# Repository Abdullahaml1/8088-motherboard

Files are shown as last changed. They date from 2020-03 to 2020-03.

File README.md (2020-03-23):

# 8088-motherboard
This is the full design files for the  20x20 cm^2 8088 motheboard project.

The project aims to uplaoad a code on the flash memories of the intel 8088 micro processor  with 8051 controller. In addtion input outpu module addes to test inputs.

The motherboard consists of 5 parts:

1. The motherboard it self with the 8088 in its center. 
2. The 80851 module.
3. The input output module.
4. two memories.

# Table of Content

* [Full desing](#Full-Desing)
* [8088 Motherboard](#8088-Motherboard)
* [8051 Module](#8051-Module)
* [Input Output Module](#Input-Output-Module)
* [Memories](#Memories)

## Full Desing

top view

side view

## 8088 Motherboard

empty mothrboard

## 8051 Module

8051 module

## Input Output Module

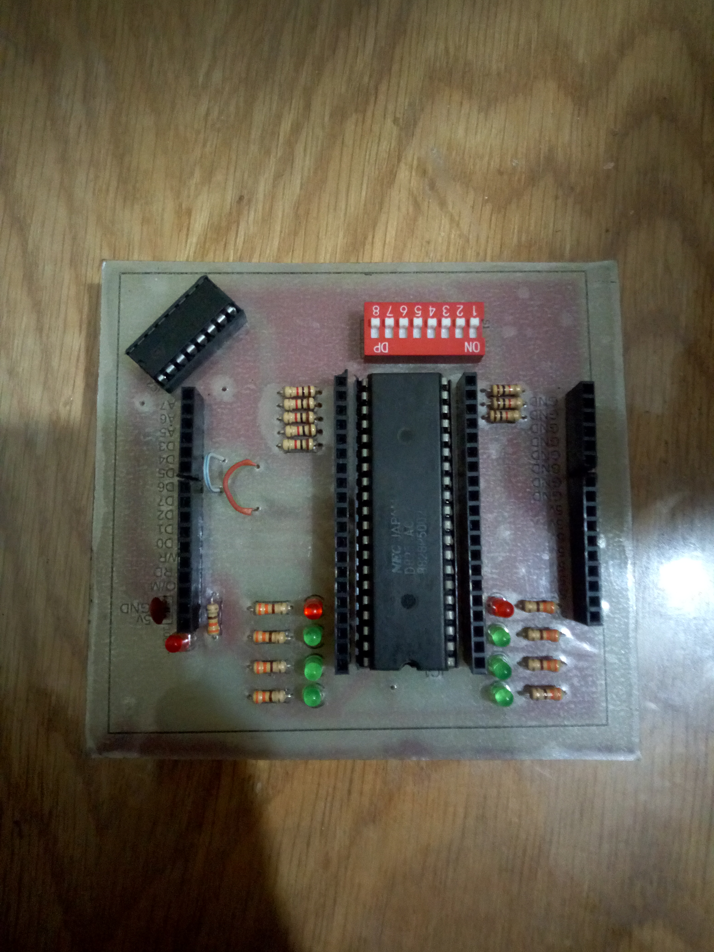
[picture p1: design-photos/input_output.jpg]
input output module


## Memories 

Memories

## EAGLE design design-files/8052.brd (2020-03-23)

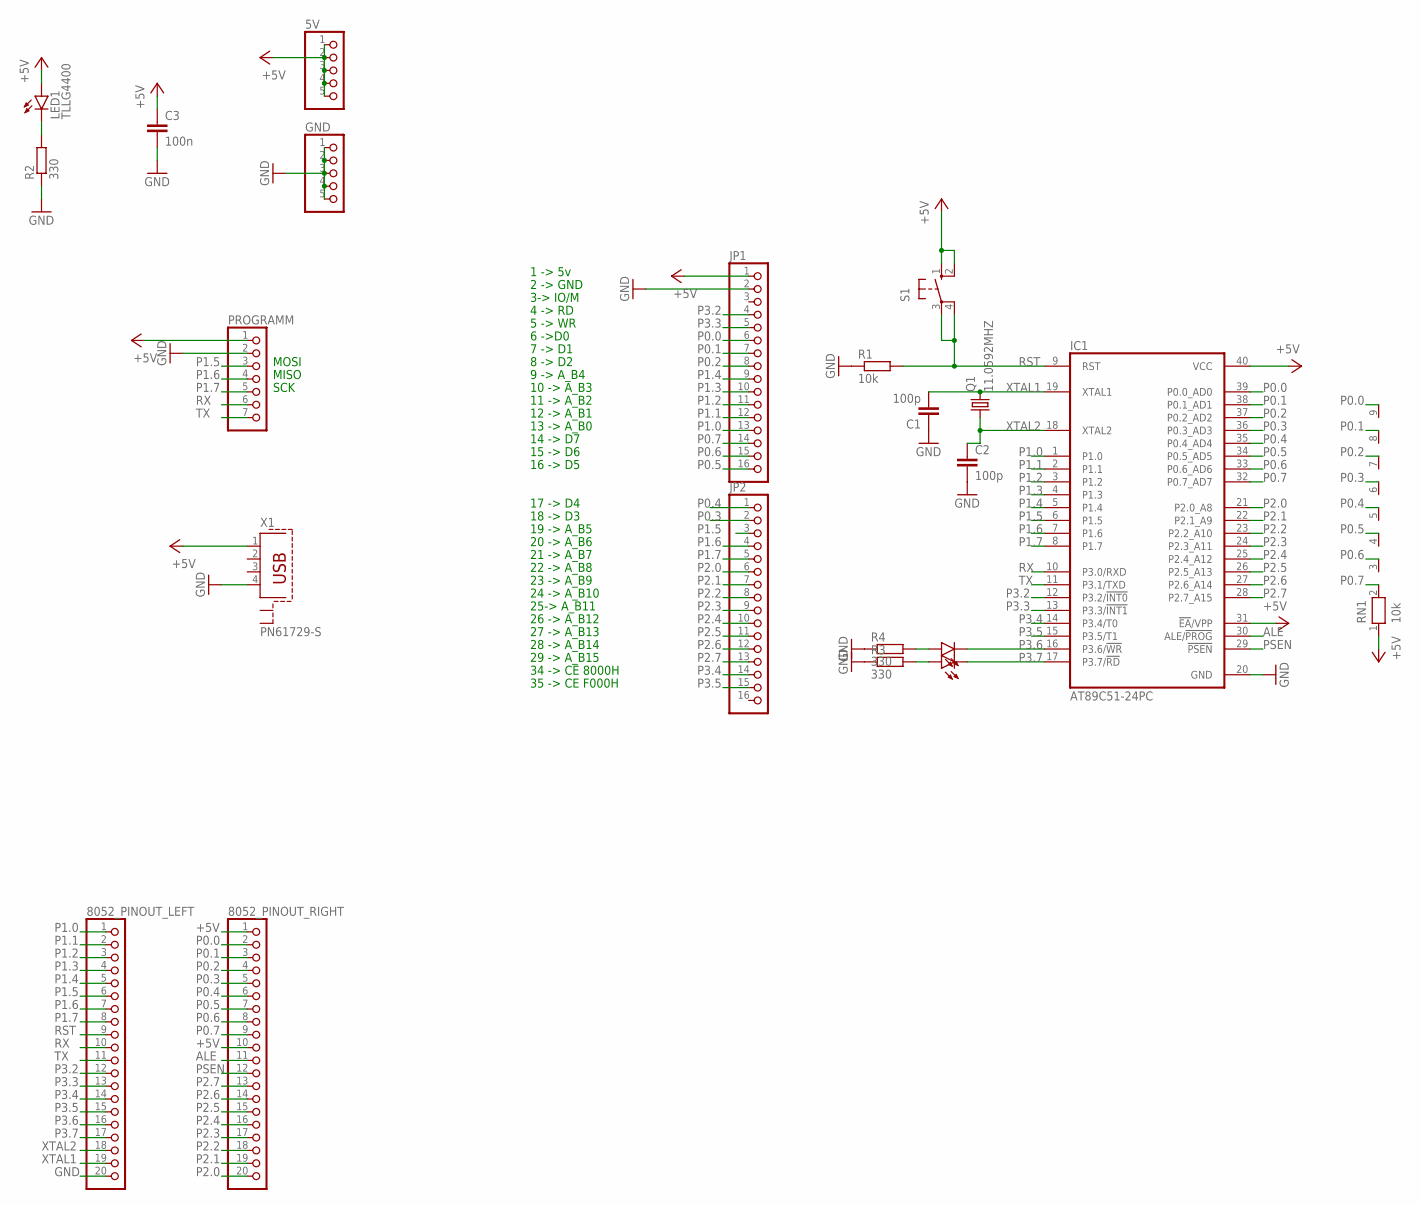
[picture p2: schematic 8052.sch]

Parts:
5V: PINHD-1X5; 1X05
8052_PINOUT_LEFT, 8052_PINOUT_RIGHT: PINHD-1X20; 1X20
C1, C2: 100p; C025-024X044
C3: 100n; C025-025X050
GND: PINHD-1X5; 1X05
IC1: AT89C51-24PC; DIL40
JP1, JP2: PINHD-1X16; 1X16
LED1, LED2, LED3: TLLG4400; LED3MM
PROGRAMM: PINHD-1X7/90; 1X07/90
Q1: 11.0592MHZ; HC49/S
R1: 10k; 0207/7
R2, R3, R4: 330; 0207/7
RN1: 10k; RN-9
S1: 10-XX; B3F-10XX
X1: PN61729-S

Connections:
+5V: 5V.1, 5V.2, 5V.3, 5V.4, 5V.5, 8052_PINOUT_RIGHT.1, 8052_PINOUT_RIGHT.10, C3.1, IC1.31 (!EA!/VPP), IC1.40 (VCC), JP1.1, LED1.A, PROGRAMM.1, RN1.1, S1.1 (S), S1.2 (S1), X1.1
ALE: 8052_PINOUT_RIGHT.11, IC1.30 (ALE/!PROG)
GND: 8052_PINOUT_LEFT.20, C1.1, C2.2, C3.2, GND.1, GND.2, GND.3, GND.4, GND.5, IC1.20 (GND), JP1.2, PROGRAMM.2, R1.1, R2.1, R3.1, R4.1, X1.4
unnamed: LED1.K (C), R2.2
unnamed: LED3.A, R3.2
unnamed: LED2.A, R4.2
P0.0: 8052_PINOUT_RIGHT.2, IC1.39 (P0.0_AD0), JP1.6, RN1.9
P0.1: 8052_PINOUT_RIGHT.3, IC1.38 (P0.1_AD1), JP1.7, RN1.8
P0.2: 8052_PINOUT_RIGHT.4, IC1.37 (P0.2_AD2), JP1.8, RN1.7
P0.3: 8052_PINOUT_RIGHT.5, IC1.36 (P0.3_AD3), JP2.2, RN1.6
P0.4: 8052_PINOUT_RIGHT.6, IC1.35 (P0.4_AD4), JP2.1, RN1.5
P0.5: 8052_PINOUT_RIGHT.7, IC1.34 (P0.5_AD5), JP1.16, RN1.4
P0.6: 8052_PINOUT_RIGHT.8, IC1.33 (P0.6_AD6), JP1.15, RN1.3
P0.7: 8052_PINOUT_RIGHT.9, IC1.32 (P0.7_AD7), JP1.14, RN1.2
P1.0: 8052_PINOUT_LEFT.1, IC1.1 (P1.0), JP1.13
P1.1: 8052_PINOUT_LEFT.2, IC1.2 (P1.1), JP1.12
P1.2: 8052_PINOUT_LEFT.3, IC1.3 (P1.2), JP1.11
P1.3: 8052_PINOUT_LEFT.4, IC1.4 (P1.3), JP1.10
P1.4: 8052_PINOUT_LEFT.5, IC1.5 (P1.4), JP1.9
P1.5: 8052_PINOUT_LEFT.6, IC1.6 (P1.5), JP2.3, PROGRAMM.3
P1.6: 8052_PINOUT_LEFT.7, IC1.7 (P1.6), JP2.4, PROGRAMM.4
P1.7: 8052_PINOUT_LEFT.8, IC1.8 (P1.7), JP2.5, PROGRAMM.5
P2.0: 8052_PINOUT_RIGHT.20, IC1.21 (P2.0_A8), JP2.6
P2.1: 8052_PINOUT_RIGHT.19, IC1.22 (P2.1_A9), JP2.7
P2.2: 8052_PINOUT_RIGHT.18, IC1.23 (P2.2_A10), JP2.8
P2.3: 8052_PINOUT_RIGHT.17, IC1.24 (P2.3_A11), JP2.9
P2.4: 8052_PINOUT_RIGHT.16, IC1.25 (P2.4_A12), JP2.10
P2.5: 8052_PINOUT_RIGHT.15, IC1.26 (P2.5_A13), JP2.11
P2.6: 8052_PINOUT_RIGHT.14, IC1.27 (P2.6_A14), JP2.12
P2.7: 8052_PINOUT_RIGHT.13, IC1.28 (P2.7_A15), JP2.13
P3.2: 8052_PINOUT_LEFT.12, IC1.12 (P3.2/!INT0), JP1.4
P3.3: 8052_PINOUT_LEFT.13, IC1.13 (P3.3/!INT1), JP1.5
P3.4: 8052_PINOUT_LEFT.14, IC1.14 (P3.4/T0), JP2.14
P3.5: 8052_PINOUT_LEFT.15, IC1.15 (P3.5/T1), JP2.15
P3.6: 8052_PINOUT_LEFT.16, IC1.16 (P3.6/!WR), LED2.K (C)
P3.7: 8052_PINOUT_LEFT.17, IC1.17 (P3.7/!RD), LED3.K (C)
PSEN: 8052_PINOUT_RIGHT.12, IC1.29 (!PSEN)
RST: 8052_PINOUT_LEFT.9, IC1.9 (RST), R1.2, S1.3, S1.4 (P1)
RX: 8052_PINOUT_LEFT.10, IC1.10 (P3.0/RXD), PROGRAMM.6
TX: 8052_PINOUT_LEFT.11, IC1.11 (P3.1/TXD), PROGRAMM.7
XTAL1: 8052_PINOUT_LEFT.19, C1.2, IC1.19 (XTAL1), Q1.2
XTAL2: 8052_PINOUT_LEFT.18, C2.1, IC1.18 (XTAL2), Q1.1

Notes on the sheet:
3-> IO/M
6 ->D0
13 -> A_B0
14 -> D7
21 -> A_B7
22 -> A_B8
25-> A_B11
7 -> D1
8 -> D2
9 -> A_B4
10 -> A_B3
11 -> A_B2
12 -> A_B1
15 -> D6
16 -> D5
17 -> D4
18 -> D3
19 -> A_B5
20 -> A_B6
23 -> A_B9
24 -> A_B10
26 -> A_B12
27 -> A_B13
28 -> A_B14
5 -> WR
4 -> RD
1 -> 5v
2 -> GND
29 -> A_B15
34 -> CE 8000H
35 -> CE F000H
MOSI
MISO
SCK

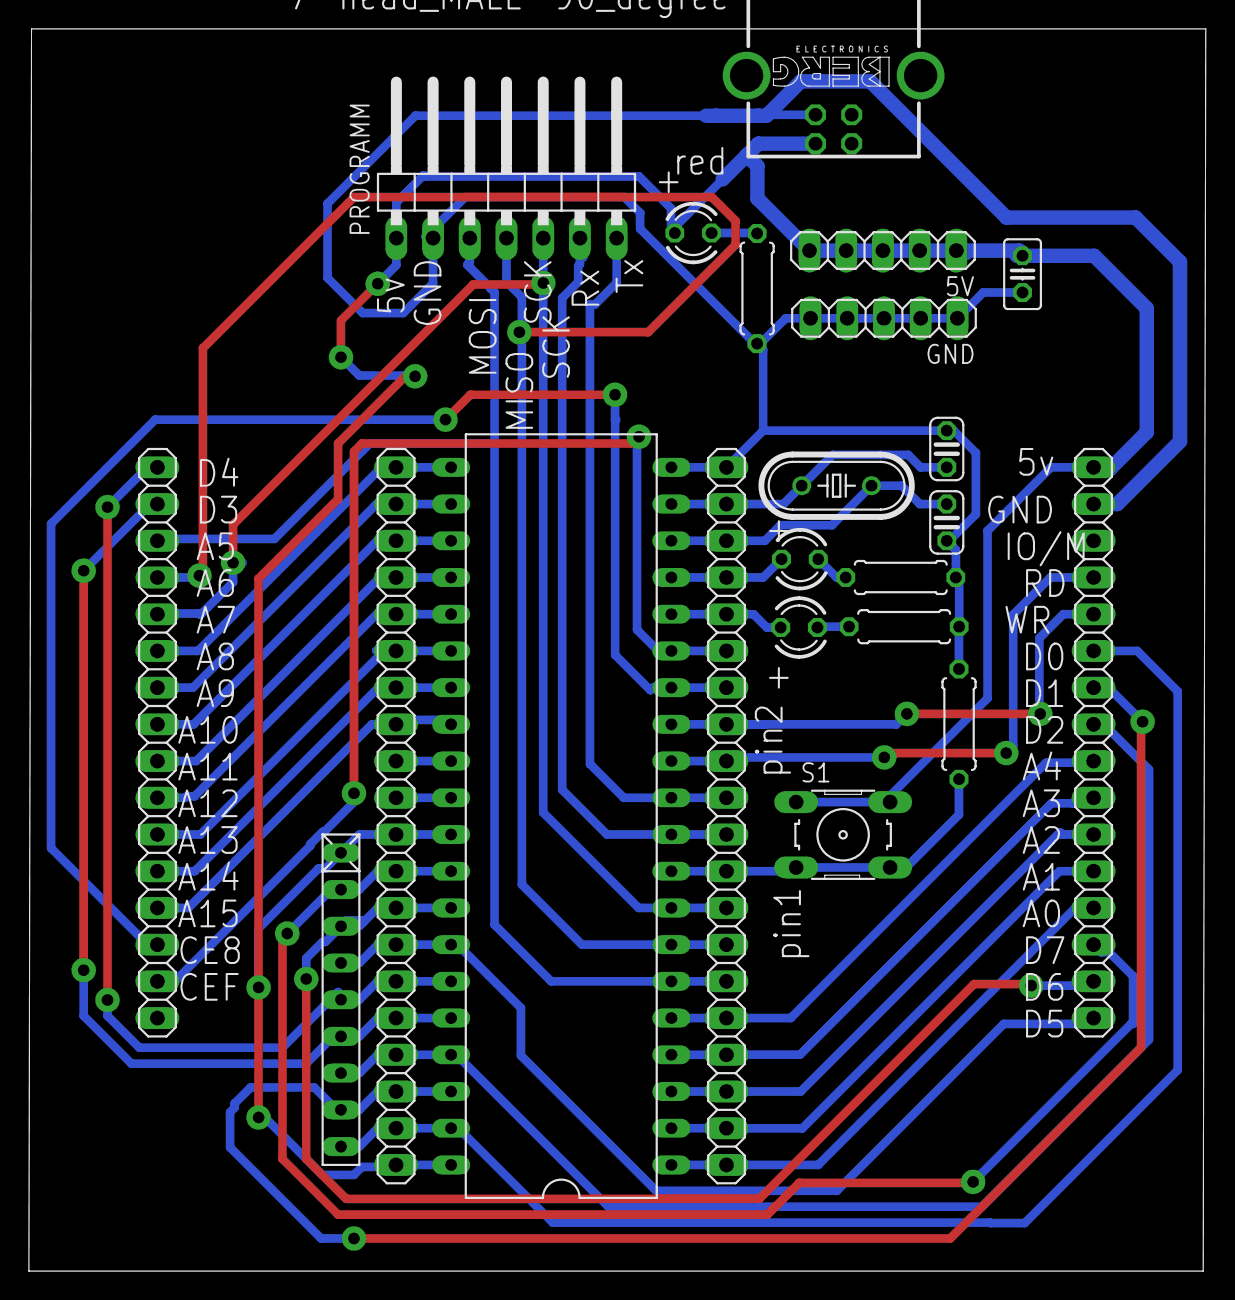
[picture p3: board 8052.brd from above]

Board: 2 copper layers, 81.4 x 85.9 mm, 22 parts (0 on the bottom side), 42 nets.

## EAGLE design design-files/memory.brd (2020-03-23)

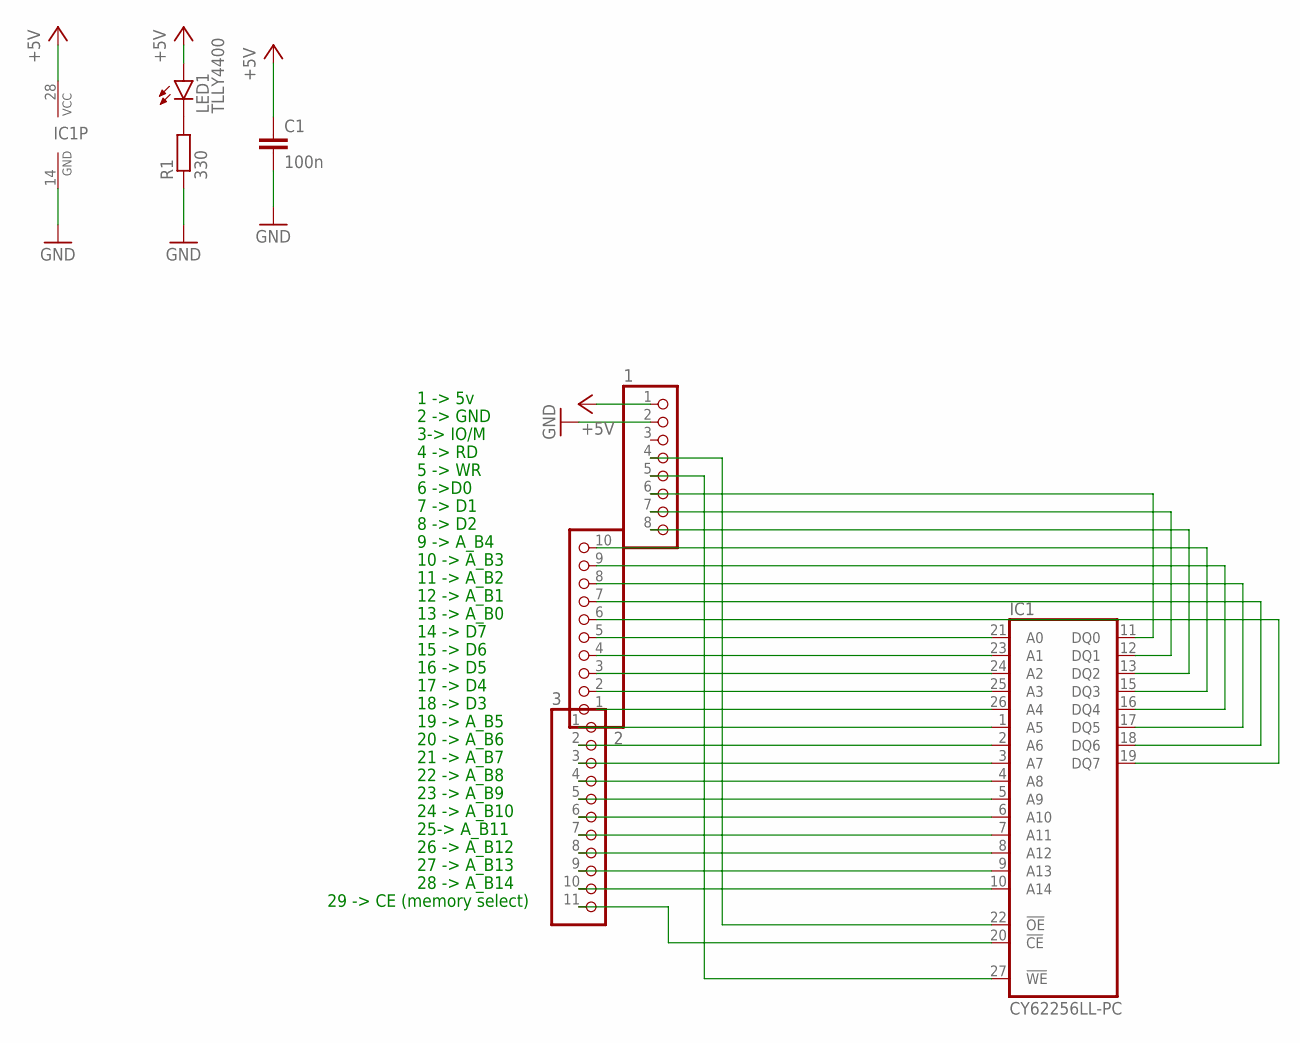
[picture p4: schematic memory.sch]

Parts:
1: PINHD-1X8/90; 1X08/90
2: PINHD-1X10/90; 1X10/90
3: PINHD-1X11/90; 1X11/90
C1: 100n; C025-025X050
IC1: CY62256LL-PC; DIL28-6
LED1: TLLY4400; LED3MM
R1: 330; 0207/7

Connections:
+5V: 1.1, C1.1, IC1.28 (VCC), LED1.A
GND: 1.2, C1.2, IC1.14 (GND), R1.1
unnamed: 2.5, IC1.21 (A0)
unnamed: 2.4, IC1.23 (A1)
unnamed: 2.3, IC1.24 (A2)
unnamed: 2.2, IC1.25 (A3)
unnamed: 2.1, IC1.26 (A4)
unnamed: 3.1, IC1.1 (A5)
unnamed: 3.2, IC1.2 (A6)
unnamed: 3.3, IC1.3 (A7)
unnamed: 3.4, IC1.4 (A8)
unnamed: 3.5, IC1.5 (A9)
unnamed: 3.6, IC1.6 (A10)
unnamed: 3.7, IC1.7 (A11)
unnamed: 3.8, IC1.8 (A12)
unnamed: 3.9, IC1.9 (A13)
unnamed: 3.10, IC1.10 (A14)
unnamed: 1.6, IC1.11 (DQ0)
unnamed: 1.7, IC1.12 (DQ1)
unnamed: 1.8, IC1.13 (DQ2)
unnamed: 2.10, IC1.15 (DQ3)
unnamed: 2.9, IC1.16 (DQ4)
unnamed: 2.8, IC1.17 (DQ5)
unnamed: 2.7, IC1.18 (DQ6)
unnamed: 2.6, IC1.19 (DQ7)
unnamed: LED1.K (C), R1.2
unnamed: 1.5, IC1.27 (!WE)
unnamed: 1.4, IC1.22 (!OE)
unnamed: 3.11, IC1.20 (!CE)

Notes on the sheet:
3-> IO/M
6 ->D0
13 -> A_B0
14 -> D7
21 -> A_B7
22 -> A_B8
25-> A_B11
7 -> D1
8 -> D2
9 -> A_B4
10 -> A_B3
11 -> A_B2
12 -> A_B1
15 -> D6
16 -> D5
17 -> D4
18 -> D3
19 -> A_B5
20 -> A_B6
23 -> A_B9
24 -> A_B10
26 -> A_B12
27 -> A_B13
28 -> A_B14
29 -> CE (memory select)
5 -> WR
4 -> RD
1 -> 5v
2 -> GND

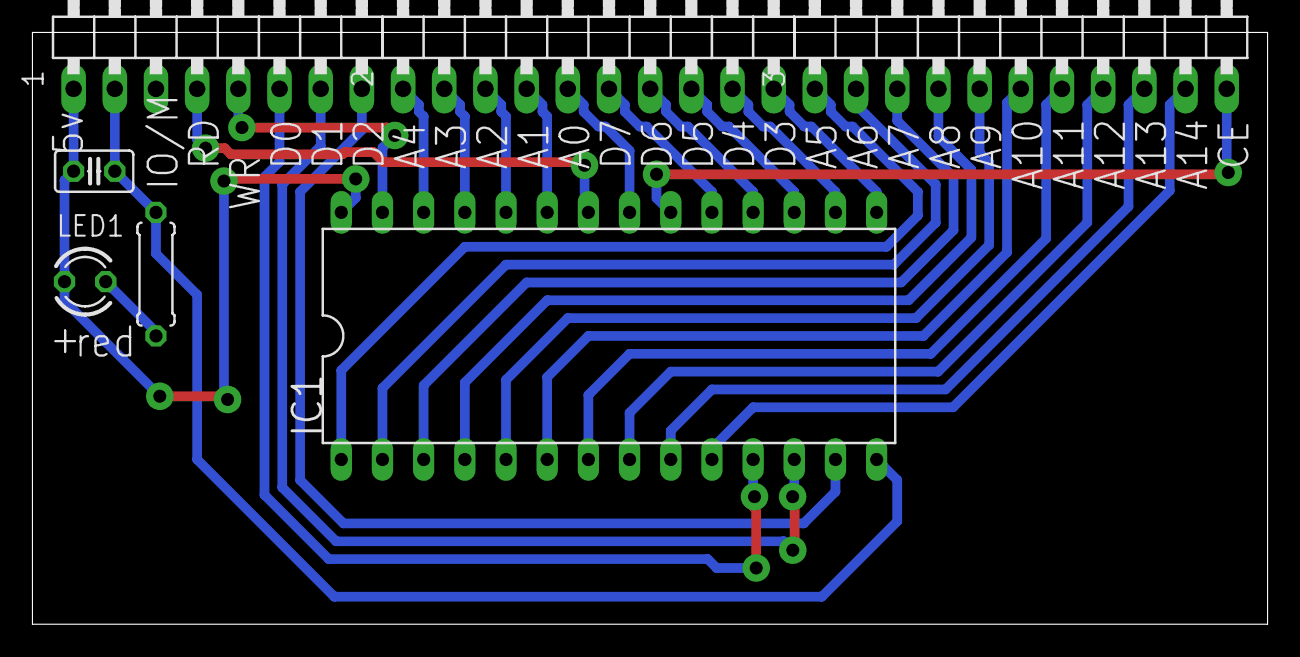
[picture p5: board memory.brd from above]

Board: 2 copper layers, 76.2 x 36.5 mm, 7 parts (0 on the bottom side), 29 nets.

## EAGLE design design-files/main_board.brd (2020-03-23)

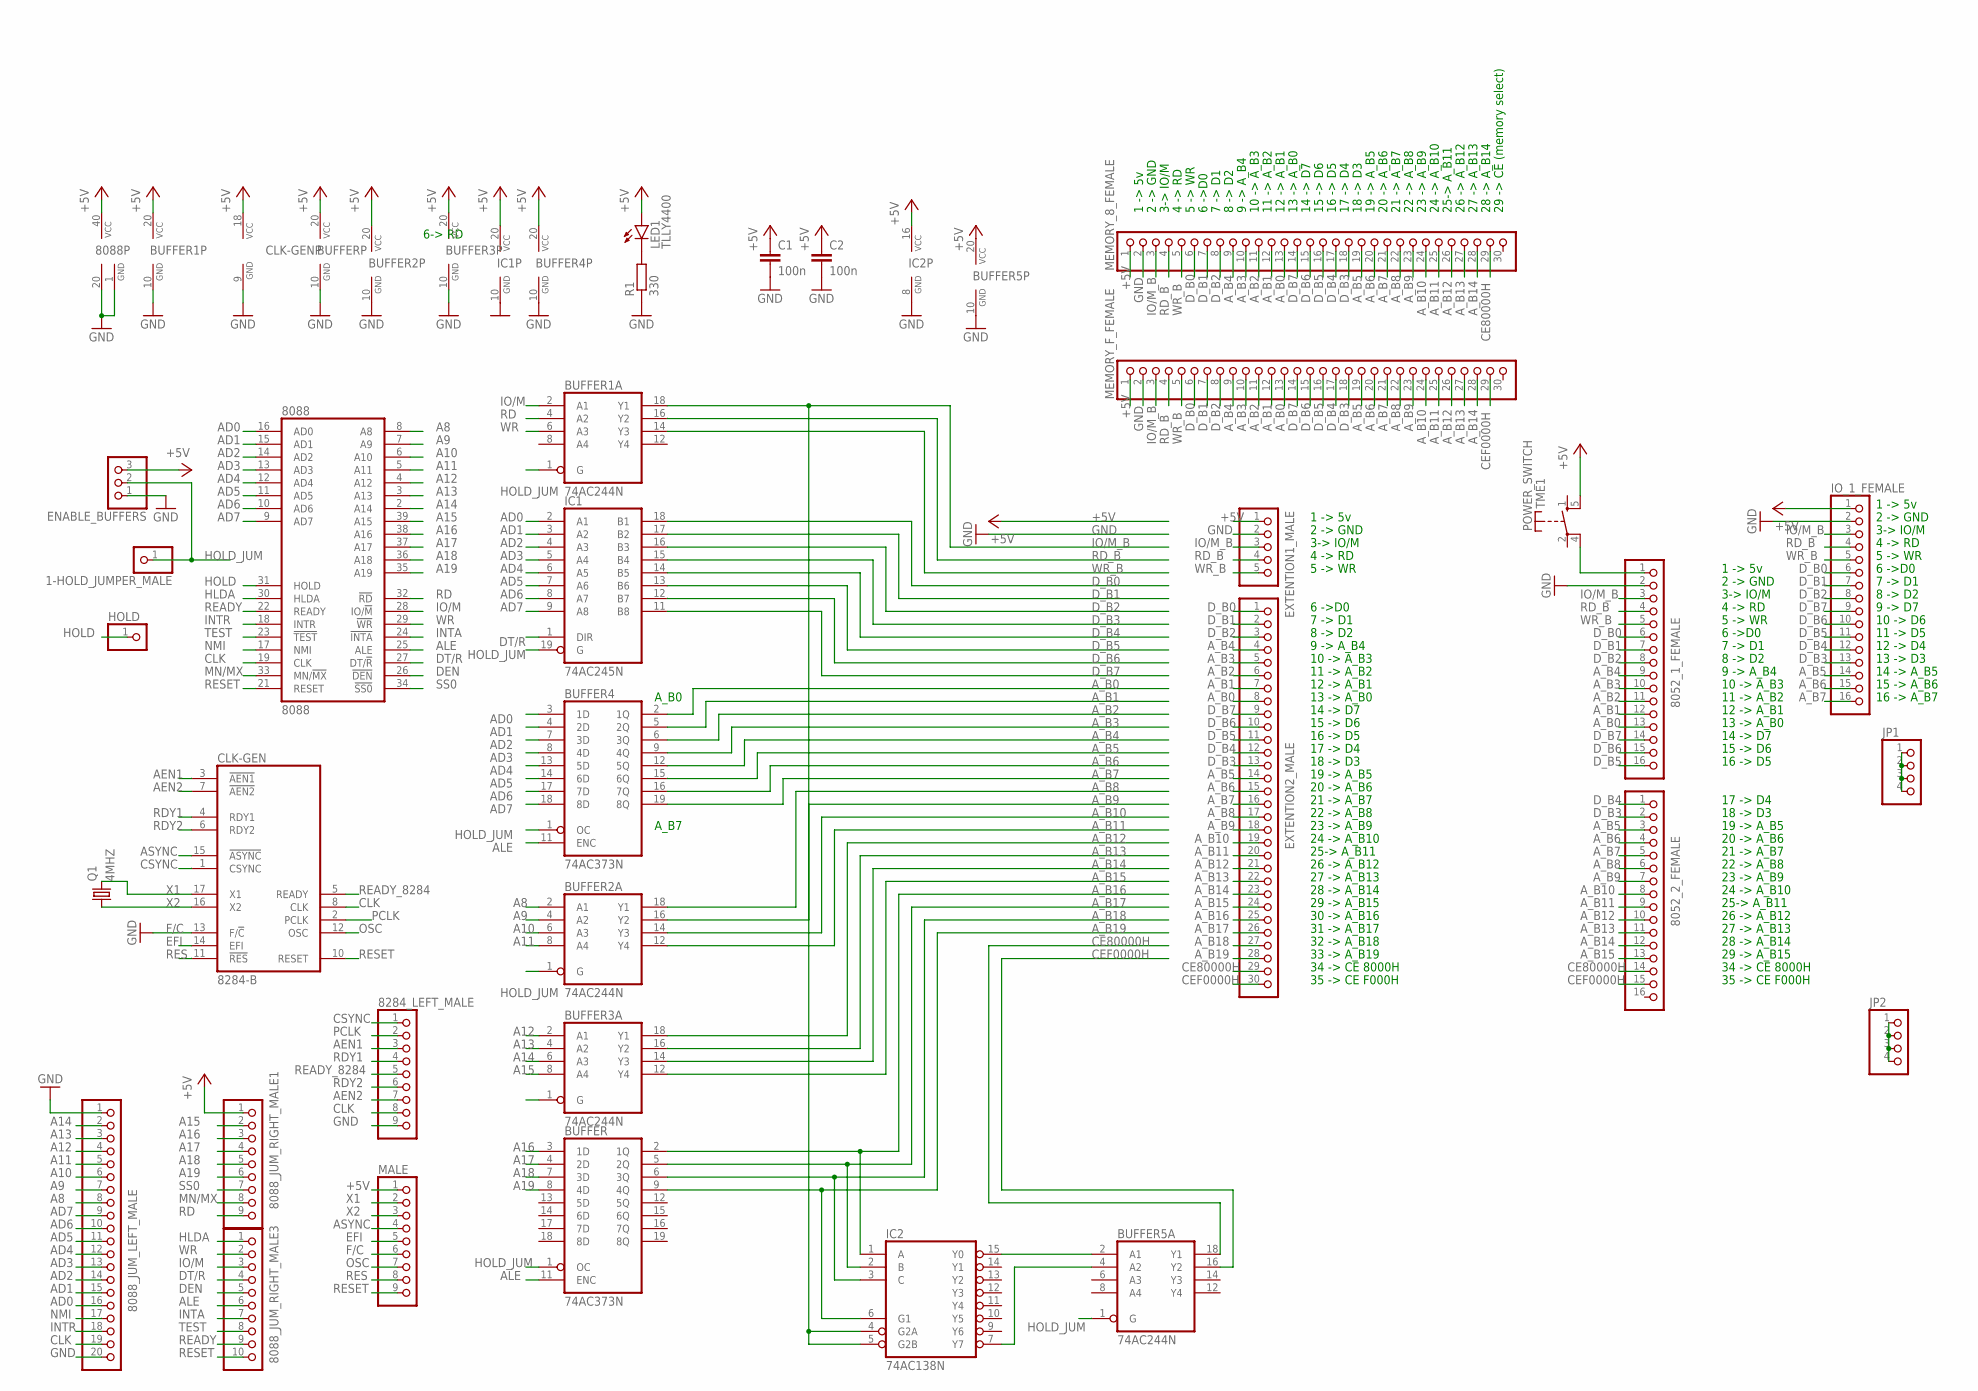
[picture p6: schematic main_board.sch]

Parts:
1-HOLD_JUMPER_MALE: PINHD-1X1; 1X01
8052_1_FEMALE, 8052_2_FEMALE: PINHD-1X16; 1X16
8088: 8088; DIL40
8088_JUM_LEFT_MALE: PINHD-1X20; 1X20
8088_JUM_RIGHT_MALE1, 8284_LEFT_MALE: PINHD-1X9; 1X09
8088_JUM_RIGHT_MALE3: PINHD-1X10; 1X10
BUFFER, BUFFER4: 74AC373N; DIL20
BUFFER1, BUFFER2, BUFFER3, BUFFER5: 74AC244N; DIL20
C1, C2: 100n; C025-025X050
CLK-GEN: 8284-B; DIL18
ENABLE_BUFFERS: PINHD-1X3; 1X03
EXTENTION1_MALE: PINHD-1X5; 1X05
EXTENTION2_MALE: PINHD-1X30; 1X30
HOLD: PINHD-1X1; 1X01
IC1: 74AC245N; DIL20
IC2: 74AC138N; DIL16
IO_1_FEMALE: PINHD-1X16; 1X16
JP1, JP2: PINHD-1X4; 1X04
LED1: TLLY4400; LED3MM
MALE: PINHD-1X9; 1X09
MEMORY_8_FEMALE: PINHD-1X30; 1X30
MEMORY_F_FEMALE: PINHD-1X30; 1X30
POWER_SWITCH: TME1
Q1: 4MHZ; HC49/S
R1: 330; 0204/5

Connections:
+5V: 8088.40 (VCC), 8088_JUM_RIGHT_MALE1.1, BUFFER.20 (VCC), BUFFER1.20 (VCC), BUFFER2.20 (VCC), BUFFER3.20 (VCC), BUFFER4.20 (VCC), BUFFER5.20 (VCC), C1.1, C2.1, CLK-GEN.18 (VCC), ENABLE_BUFFERS.3, EXTENTION1_MALE.1, IC1.20 (VCC), IC2.16 (VCC), IO_1_FEMALE.1, LED1.A, MALE.1, MEMORY_8_FEMALE.1, MEMORY_F_FEMALE.1, POWER_SWITCH.5 (S)
A8: 8088.8 (A8), 8088_JUM_LEFT_MALE.8, BUFFER2.2 (A1)
A9: 8088.7 (A9), 8088_JUM_LEFT_MALE.7, BUFFER2.4 (A2)
A10: 8088.6 (A10), 8088_JUM_LEFT_MALE.6, BUFFER2.6 (A3)
A11: 8088.5 (A11), 8088_JUM_LEFT_MALE.5, BUFFER2.8 (A4)
A12: 8088.4 (A12), 8088_JUM_LEFT_MALE.4, BUFFER3.2 (A1)
A13: 8088.3 (A13), 8088_JUM_LEFT_MALE.3, BUFFER3.4 (A2)
A14: 8088.2 (A14), 8088_JUM_LEFT_MALE.2, BUFFER3.6 (A3)
A15: 8088.39 (A15), 8088_JUM_RIGHT_MALE1.2, BUFFER3.8 (A4)
A16: 8088.38 (A16), 8088_JUM_RIGHT_MALE1.3, BUFFER.3 (1D)
A17: 8088.37 (A17), 8088_JUM_RIGHT_MALE1.4, BUFFER.4 (2D)
A18: 8088.36 (A18), 8088_JUM_RIGHT_MALE1.5, BUFFER.7 (3D)
A19: 8088.35 (A19), 8088_JUM_RIGHT_MALE1.6, BUFFER.8 (4D)
AD0: 8088.16 (AD0), 8088_JUM_LEFT_MALE.16, BUFFER4.3 (1D), IC1.2 (A1)
AD1: 8088.15 (AD1), 8088_JUM_LEFT_MALE.15, BUFFER4.4 (2D), IC1.3 (A2)
AD2: 8088.14 (AD2), 8088_JUM_LEFT_MALE.14, BUFFER4.7 (3D), IC1.4 (A3)
AD3: 8088.13 (AD3), 8088_JUM_LEFT_MALE.13, BUFFER4.8 (4D), IC1.5 (A4)
AD4: 8088.12 (AD4), 8088_JUM_LEFT_MALE.12, BUFFER4.13 (5D), IC1.6 (A5)
AD5: 8088.11 (AD5), 8088_JUM_LEFT_MALE.11, BUFFER4.14 (6D), IC1.7 (A6)
AD6: 8088.10 (AD6), 8088_JUM_LEFT_MALE.10, BUFFER4.17 (7D), IC1.8 (A7)
AD7: 8088.9 (AD7), 8088_JUM_LEFT_MALE.9, BUFFER4.18 (8D), IC1.9 (A8)
AEN1: 8284_LEFT_MALE.3, CLK-GEN.3 (!AEN1)
AEN2: 8284_LEFT_MALE.7, CLK-GEN.7 (!AEN2)
ALE: 8088.25 (ALE), 8088_JUM_RIGHT_MALE3.6, BUFFER.11 (ENC), BUFFER4.11 (ENC)
ASYNC: CLK-GEN.15 (!ASYNC), MALE.4
A_B0: 8052_1_FEMALE.13, BUFFER4.2 (1Q), EXTENTION2_MALE.8, MEMORY_8_FEMALE.13, MEMORY_F_FEMALE.13
A_B1: 8052_1_FEMALE.12, BUFFER4.5 (2Q), EXTENTION2_MALE.7, MEMORY_8_FEMALE.12, MEMORY_F_FEMALE.12
A_B2: 8052_1_FEMALE.11, BUFFER4.6 (3Q), EXTENTION2_MALE.6, MEMORY_8_FEMALE.11, MEMORY_F_FEMALE.11
A_B3: 8052_1_FEMALE.10, BUFFER4.9 (4Q), EXTENTION2_MALE.5, MEMORY_8_FEMALE.10, MEMORY_F_FEMALE.10
A_B4: 8052_1_FEMALE.9, BUFFER4.12 (5Q), EXTENTION2_MALE.4, MEMORY_8_FEMALE.9, MEMORY_F_FEMALE.9
A_B5: 8052_2_FEMALE.3, BUFFER4.15 (6Q), EXTENTION2_MALE.14, IO_1_FEMALE.14, MEMORY_8_FEMALE.19, MEMORY_F_FEMALE.19
A_B6: 8052_2_FEMALE.4, BUFFER4.16 (7Q), EXTENTION2_MALE.15, IO_1_FEMALE.15, MEMORY_8_FEMALE.20, MEMORY_F_FEMALE.20
A_B7: 8052_2_FEMALE.5, BUFFER4.19 (8Q), EXTENTION2_MALE.16, IO_1_FEMALE.16, MEMORY_8_FEMALE.21, MEMORY_F_FEMALE.21
A_B8: 8052_2_FEMALE.6, BUFFER2.18 (Y1), EXTENTION2_MALE.17, MEMORY_8_FEMALE.22, MEMORY_F_FEMALE.22
A_B9: 8052_2_FEMALE.7, BUFFER2.16 (Y2), EXTENTION2_MALE.18, MEMORY_8_FEMALE.23, MEMORY_F_FEMALE.23
A_B10: 8052_2_FEMALE.8, BUFFER2.14 (Y3), EXTENTION2_MALE.19, MEMORY_8_FEMALE.24, MEMORY_F_FEMALE.24
A_B11: 8052_2_FEMALE.9, BUFFER2.12 (Y4), EXTENTION2_MALE.20, MEMORY_8_FEMALE.25, MEMORY_F_FEMALE.25
A_B12: 8052_2_FEMALE.10, BUFFER3.18 (Y1), EXTENTION2_MALE.21, MEMORY_8_FEMALE.26, MEMORY_F_FEMALE.26
A_B13: 8052_2_FEMALE.11, BUFFER3.16 (Y2), EXTENTION2_MALE.22, MEMORY_8_FEMALE.27, MEMORY_F_FEMALE.27
A_B14: 8052_2_FEMALE.12, BUFFER3.14 (Y3), EXTENTION2_MALE.23, MEMORY_8_FEMALE.28, MEMORY_F_FEMALE.28
A_B15: 8052_2_FEMALE.13, BUFFER3.12 (Y4), EXTENTION2_MALE.24
A_B16: BUFFER.2 (1Q), EXTENTION2_MALE.25, IC2.1 (A)
A_B17: BUFFER.5 (2Q), EXTENTION2_MALE.26, IC2.2 (B)
A_B18: BUFFER.6 (3Q), EXTENTION2_MALE.27, IC2.3 (C)
A_B19: BUFFER.9 (4Q), EXTENTION2_MALE.28, IC2.6 (G1)
CE80000H: 8052_2_FEMALE.14, BUFFER5.18 (Y1), EXTENTION2_MALE.29, MEMORY_8_FEMALE.29
CEF0000H: 8052_2_FEMALE.15, BUFFER5.16 (Y2), EXTENTION2_MALE.30, MEMORY_F_FEMALE.29
CLK: 8088.19 (CLK), 8088_JUM_LEFT_MALE.19, 8284_LEFT_MALE.8, CLK-GEN.8 (CLK)
CSYNC: 8284_LEFT_MALE.1, CLK-GEN.1 (CSYNC)
DEN: 8088.26 (!DEN), 8088_JUM_RIGHT_MALE3.5
DT/R: 8088.27 (DT/!R), 8088_JUM_RIGHT_MALE3.4, IC1.1 (DIR)
D_B0: 8052_1_FEMALE.6, EXTENTION2_MALE.1, IC1.18 (B1), IO_1_FEMALE.6, MEMORY_8_FEMALE.6, MEMORY_F_FEMALE.6
D_B1: 8052_1_FEMALE.7, EXTENTION2_MALE.2, IC1.17 (B2), IO_1_FEMALE.7, MEMORY_8_FEMALE.7, MEMORY_F_FEMALE.7
D_B2: 8052_1_FEMALE.8, EXTENTION2_MALE.3, IC1.16 (B3), IO_1_FEMALE.8, MEMORY_8_FEMALE.8, MEMORY_F_FEMALE.8
D_B3: 8052_2_FEMALE.2, EXTENTION2_MALE.13, IC1.15 (B4), IO_1_FEMALE.13, MEMORY_8_FEMALE.18, MEMORY_F_FEMALE.18
D_B4: 8052_2_FEMALE.1, EXTENTION2_MALE.12, IC1.14 (B5), IO_1_FEMALE.12, MEMORY_8_FEMALE.17, MEMORY_F_FEMALE.17
D_B5: 8052_1_FEMALE.16, EXTENTION2_MALE.11, IC1.13 (B6), IO_1_FEMALE.11, MEMORY_8_FEMALE.16, MEMORY_F_FEMALE.16
D_B6: 8052_1_FEMALE.15, EXTENTION2_MALE.10, IC1.12 (B7), IO_1_FEMALE.10, MEMORY_8_FEMALE.15, MEMORY_F_FEMALE.15
D_B7: 8052_1_FEMALE.14, EXTENTION2_MALE.9, IC1.11 (B8), IO_1_FEMALE.9, MEMORY_8_FEMALE.14, MEMORY_F_FEMALE.14
EFI: CLK-GEN.14 (EFI), MALE.5
F/C: CLK-GEN.13 (F/!C), MALE.6
GND: 8052_1_FEMALE.2, 8088.1 (GND), 8088.20 (GND), 8088_JUM_LEFT_MALE.1, 8088_JUM_LEFT_MALE.20, 8284_LEFT_MALE.9, BUFFER.10 (GND), BUFFER1.10 (GND), BUFFER2.10 (GND), BUFFER3.10 (GND), BUFFER4.10 (GND), BUFFER5.10 (GND), C1.2, C2.2, CLK-GEN.9 (GND), ENABLE_BUFFERS.1, EXTENTION1_MALE.2, IC1.10 (GND), IC2.8 (GND), IO_1_FEMALE.2, MEMORY_8_FEMALE.2, MEMORY_F_FEMALE.2, R1.1
HLDA: 8088.30 (HLDA), 8088_JUM_RIGHT_MALE3.1
HOLD: 8088.31 (HOLD), HOLD.1
HOLD_JUM: 1-HOLD_JUMPER_MALE.1, BUFFER.1 (OC), BUFFER1.1 (G), BUFFER2.1 (G), BUFFER4.1 (OC), BUFFER5.1 (G), ENABLE_BUFFERS.2, IC1.19 (G)
INTA: 8088.24 (!INTA), 8088_JUM_RIGHT_MALE3.7
INTR: 8088.18 (INTR), 8088_JUM_LEFT_MALE.18
IO/M: 8088.28 (IO/!M), 8088_JUM_RIGHT_MALE3.3, BUFFER1.2 (A1)
IO/M_B: 8052_1_FEMALE.3, BUFFER1.18 (Y1), EXTENTION1_MALE.3, IC2.4 (G2A), IC2.5 (G2B), IO_1_FEMALE.3, MEMORY_8_FEMALE.3, MEMORY_F_FEMALE.3
MN/MX: 8088.33 (MN/!MX), 8088_JUM_RIGHT_MALE1.8
unnamed: JP1.1, JP1.2, JP1.3, JP1.4
unnamed: JP2.1, JP2.2, JP2.3, JP2.4
unnamed: LED1.K (C), R1.2
unnamed: 8052_1_FEMALE.1, POWER_SWITCH.4
unnamed: BUFFER5.2 (A1), IC2.15 (Y0)
unnamed: BUFFER5.4 (A2), IC2.7 (Y7)
NMI: 8088.17 (NMI), 8088_JUM_LEFT_MALE.17
OSC: CLK-GEN.12 (OSC), MALE.7
PCLK: 8284_LEFT_MALE.2, CLK-GEN.2 (PCLK)
RD: 8088.32 (!RD), 8088_JUM_RIGHT_MALE1.9, BUFFER1.4 (A2)
RDY1: 8284_LEFT_MALE.4, CLK-GEN.4 (RDY1)
RDY2: 8284_LEFT_MALE.6, CLK-GEN.6 (RDY2)
RD_B: 8052_1_FEMALE.4, BUFFER1.16 (Y2), EXTENTION1_MALE.4, IO_1_FEMALE.4, MEMORY_8_FEMALE.4, MEMORY_F_FEMALE.4
READY: 8088.22 (READY), 8088_JUM_RIGHT_MALE3.9
READY_8284: 8284_LEFT_MALE.5, CLK-GEN.5 (READY)
RES: CLK-GEN.11 (!RES), MALE.8
RESET: 8088.21 (RESET), 8088_JUM_RIGHT_MALE3.10, CLK-GEN.10 (RESET), MALE.9
SS0: 8088.34 (!SS0), 8088_JUM_RIGHT_MALE1.7
TEST: 8088.23 (!TEST), 8088_JUM_RIGHT_MALE3.8
WR: 8088.29 (!WR), 8088_JUM_RIGHT_MALE3.2, BUFFER1.6 (A3)
WR_B: 8052_1_FEMALE.5, BUFFER1.14 (Y3), EXTENTION1_MALE.5, IO_1_FEMALE.5, MEMORY_8_FEMALE.5, MEMORY_F_FEMALE.5
X1: CLK-GEN.17 (X1), MALE.2, Q1.2
X2: CLK-GEN.16 (X2), MALE.3, Q1.1

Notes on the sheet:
A_B0
A_B7
6-> RD
3-> IO/M
6 ->D0
13 -> A_B0
14 -> D7
21 -> A_B7
22 -> A_B8
25-> A_B11
7 -> D1
8 -> D2
9 -> A_B4
10 -> A_B3
11 -> A_B2
12 -> A_B1
15 -> D6
16 -> D5
17 -> D4
18 -> D3
19 -> A_B5
20 -> A_B6
23 -> A_B9
24 -> A_B10
26 -> A_B12
27 -> A_B13
28 -> A_B14
5 -> WR
4 -> RD
1 -> 5v
2 -> GND
29 -> A_B15
30 -> A_B16
31 -> A_B17
32 -> A_B18
33 -> A_B19
34 -> CE 8000H
35 -> CE F000H
29 -> CE (memory select)
9 -> D7

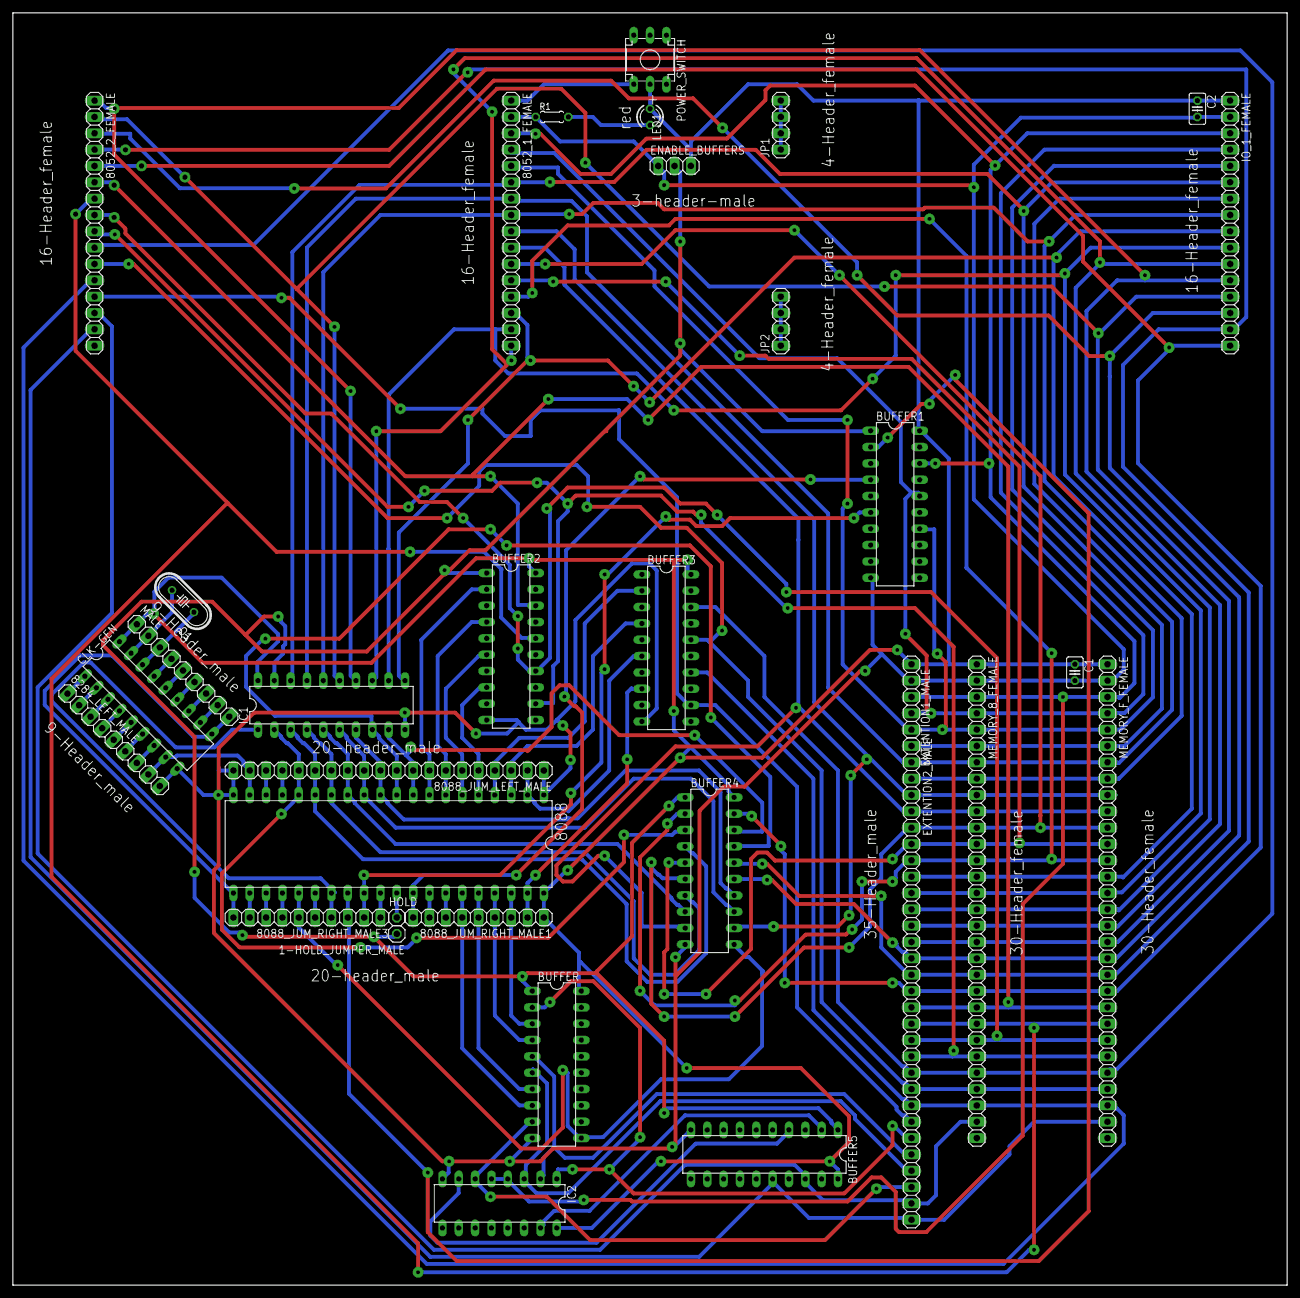
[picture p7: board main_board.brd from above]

Board: 2 copper layers, 198.1 x 197.8 mm, 33 parts (0 on the bottom side), 93 nets.

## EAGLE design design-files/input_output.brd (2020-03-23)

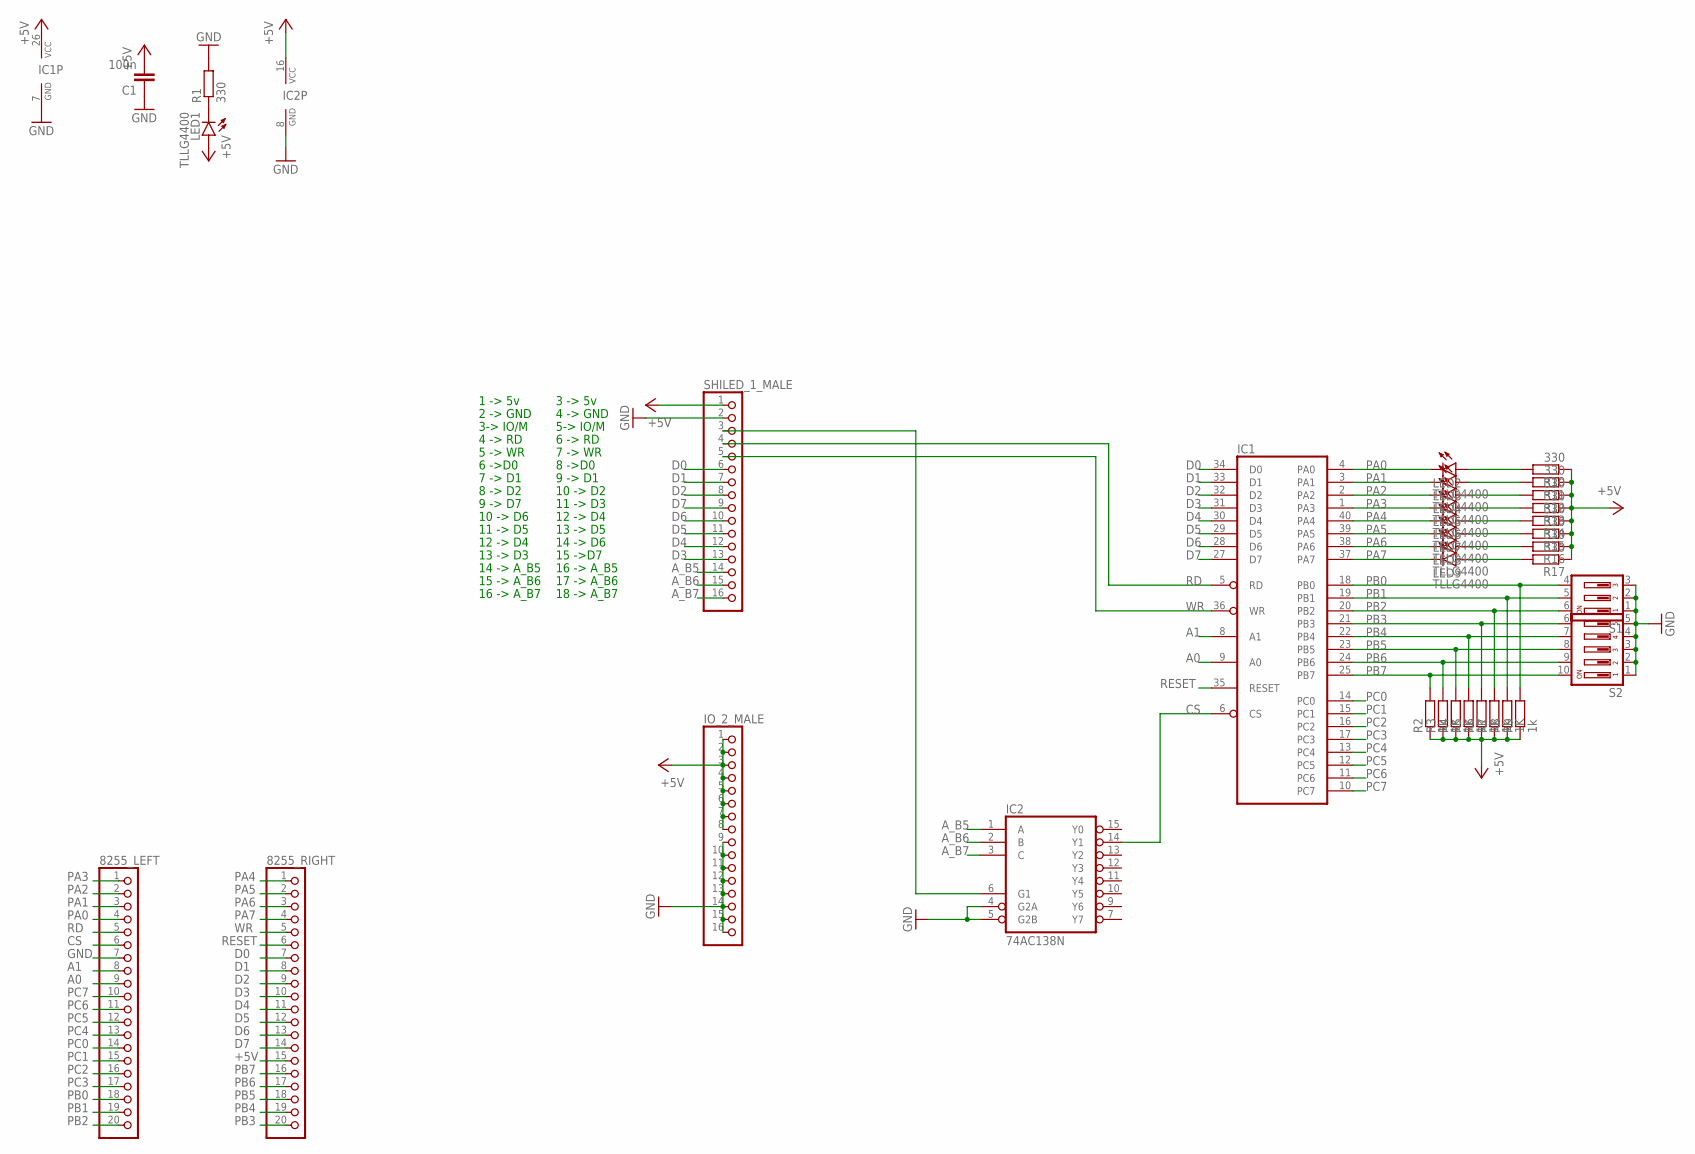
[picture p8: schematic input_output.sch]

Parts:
8255_LEFT, 8255_RIGHT: PINHD-1X20; 1X20
C1: 100n; C025-025X050
IC1: 8255A; DIL40
IC2: 74AC138N; DIL16
IO_2_MALE: PINHD-1X16; 1X16
LED1, LED2, LED3, LED4, LED5, LED6, LED7, LED8, LED9: TLLG4400; LED3MM
R1, R10, R11, R12, R13, R14, R15, R16, R17: 330; 0207/7
R2, R3, R4, R5, R6, R7, R9: 1k; 0207/7
R8: 1K; 0207/7
S1: DIP03YL
S2: DIP05YL
SHILED_1_MALE: PINHD-1X16; 1X16

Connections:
+5V: 8255_RIGHT.15, C1.2, IC1.26 (VCC), IC2.16 (VCC), IO_2_MALE.1, IO_2_MALE.2, IO_2_MALE.3, IO_2_MALE.4, IO_2_MALE.5, IO_2_MALE.6, IO_2_MALE.7, IO_2_MALE.8, LED1.A, R2.1, R3.1, R4.1, R5.1, R6.1, R7.1, R8.1, R9.1, R10.1, R11.1, R12.1, R13.1, R14.1, R15.1, R16.1, R17.1, SHILED_1_MALE.1
A0: 8255_LEFT.9, IC1.9 (A0)
A1: 8255_LEFT.8, IC1.8 (A1)
A_B5: IC2.1 (A), SHILED_1_MALE.14
A_B6: IC2.2 (B), SHILED_1_MALE.15
A_B7: IC2.3 (C), SHILED_1_MALE.16
CS: 8255_LEFT.6, IC1.6 (CS), IC2.14 (Y1)
D0: 8255_RIGHT.7, IC1.34 (D0), SHILED_1_MALE.6
D1: 8255_RIGHT.8, IC1.33 (D1), SHILED_1_MALE.7
D2: 8255_RIGHT.9, IC1.32 (D2), SHILED_1_MALE.8
D3: 8255_RIGHT.10, IC1.31 (D3), SHILED_1_MALE.13
D4: 8255_RIGHT.11, IC1.30 (D4), SHILED_1_MALE.12
D5: 8255_RIGHT.12, IC1.29 (D5), SHILED_1_MALE.11
D6: 8255_RIGHT.13, IC1.28 (D6), SHILED_1_MALE.10
D7: 8255_RIGHT.14, IC1.27 (D7), SHILED_1_MALE.9
GND: 8255_LEFT.7, C1.1, IC1.7 (GND), IC2.4 (G2A), IC2.5 (G2B), IC2.8 (GND), IO_2_MALE.9, IO_2_MALE.10, IO_2_MALE.11, IO_2_MALE.12, IO_2_MALE.13, IO_2_MALE.14, IO_2_MALE.15, IO_2_MALE.16, R1.2, S1.1, S1.2, S1.3, S2.1, S2.2, S2.3, S2.4, S2.5, SHILED_1_MALE.2
unnamed: LED1.K (C), R1.1
unnamed: LED2.A, R10.2
unnamed: LED3.A, R11.2
unnamed: LED4.A, R12.2
unnamed: LED5.A, R13.2
unnamed: LED6.A, R14.2
unnamed: LED7.A, R15.2
unnamed: LED8.A, R16.2
unnamed: LED9.A, R17.2
unnamed: IC2.6 (G1), SHILED_1_MALE.3
PA0: 8255_LEFT.4, IC1.4 (PA0), LED2.K (C)
PA1: 8255_LEFT.3, IC1.3 (PA1), LED3.K (C)
PA2: 8255_LEFT.2, IC1.2 (PA2), LED4.K (C)
PA3: 8255_LEFT.1, IC1.1 (PA3), LED5.K (C)
PA4: 8255_RIGHT.1, IC1.40 (PA4), LED6.K (C)
PA5: 8255_RIGHT.2, IC1.39 (PA5), LED7.K (C)
PA6: 8255_RIGHT.3, IC1.38 (PA6), LED8.K (C)
PA7: 8255_RIGHT.4, IC1.37 (PA7), LED9.K (C)
PB0: 8255_LEFT.18, IC1.18 (PB0), R9.2, S1.4
PB1: 8255_LEFT.19, IC1.19 (PB1), R8.2, S1.5
PB2: 8255_LEFT.20, IC1.20 (PB2), R7.2, S1.6
PB3: 8255_RIGHT.20, IC1.21 (PB3), R6.2, S2.6
PB4: 8255_RIGHT.19, IC1.22 (PB4), R5.2, S2.7
PB5: 8255_RIGHT.18, IC1.23 (PB5), R4.2, S2.8
PB6: 8255_RIGHT.17, IC1.24 (PB6), R3.2, S2.9
PB7: 8255_RIGHT.16, IC1.25 (PB7), R2.2, S2.10
PC0: 8255_LEFT.14, IC1.14 (PC0)
PC1: 8255_LEFT.15, IC1.15 (PC1)
PC2: 8255_LEFT.16, IC1.16 (PC2)
PC3: 8255_LEFT.17, IC1.17 (PC3)
PC4: 8255_LEFT.13, IC1.13 (PC4)
PC5: 8255_LEFT.12, IC1.12 (PC5)
PC6: 8255_LEFT.11, IC1.11 (PC6)
PC7: 8255_LEFT.10, IC1.10 (PC7)
RD: 8255_LEFT.5, IC1.5 (RD), SHILED_1_MALE.4
RESET: 8255_RIGHT.6, IC1.35 (RESET)
WR: 8255_RIGHT.5, IC1.36 (WR), SHILED_1_MALE.5

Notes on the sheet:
5-> IO/M
8 ->D0
15 ->D7
9 -> D1
10 -> D2
11 -> D3
12 -> D4
13 -> D5
14 -> D6
7 -> WR
6 -> RD
3 -> 5v
4 -> GND
16 -> A_B5
17 -> A_B6
18 -> A_B7
3-> IO/M
6 ->D0
7 -> D1
8 -> D2
5 -> WR
4 -> RD
1 -> 5v
2 -> GND
9 -> D7
16 -> A_B7
10 -> D6
11 -> D5
13 -> D3
14 -> A_B5
15 -> A_B6

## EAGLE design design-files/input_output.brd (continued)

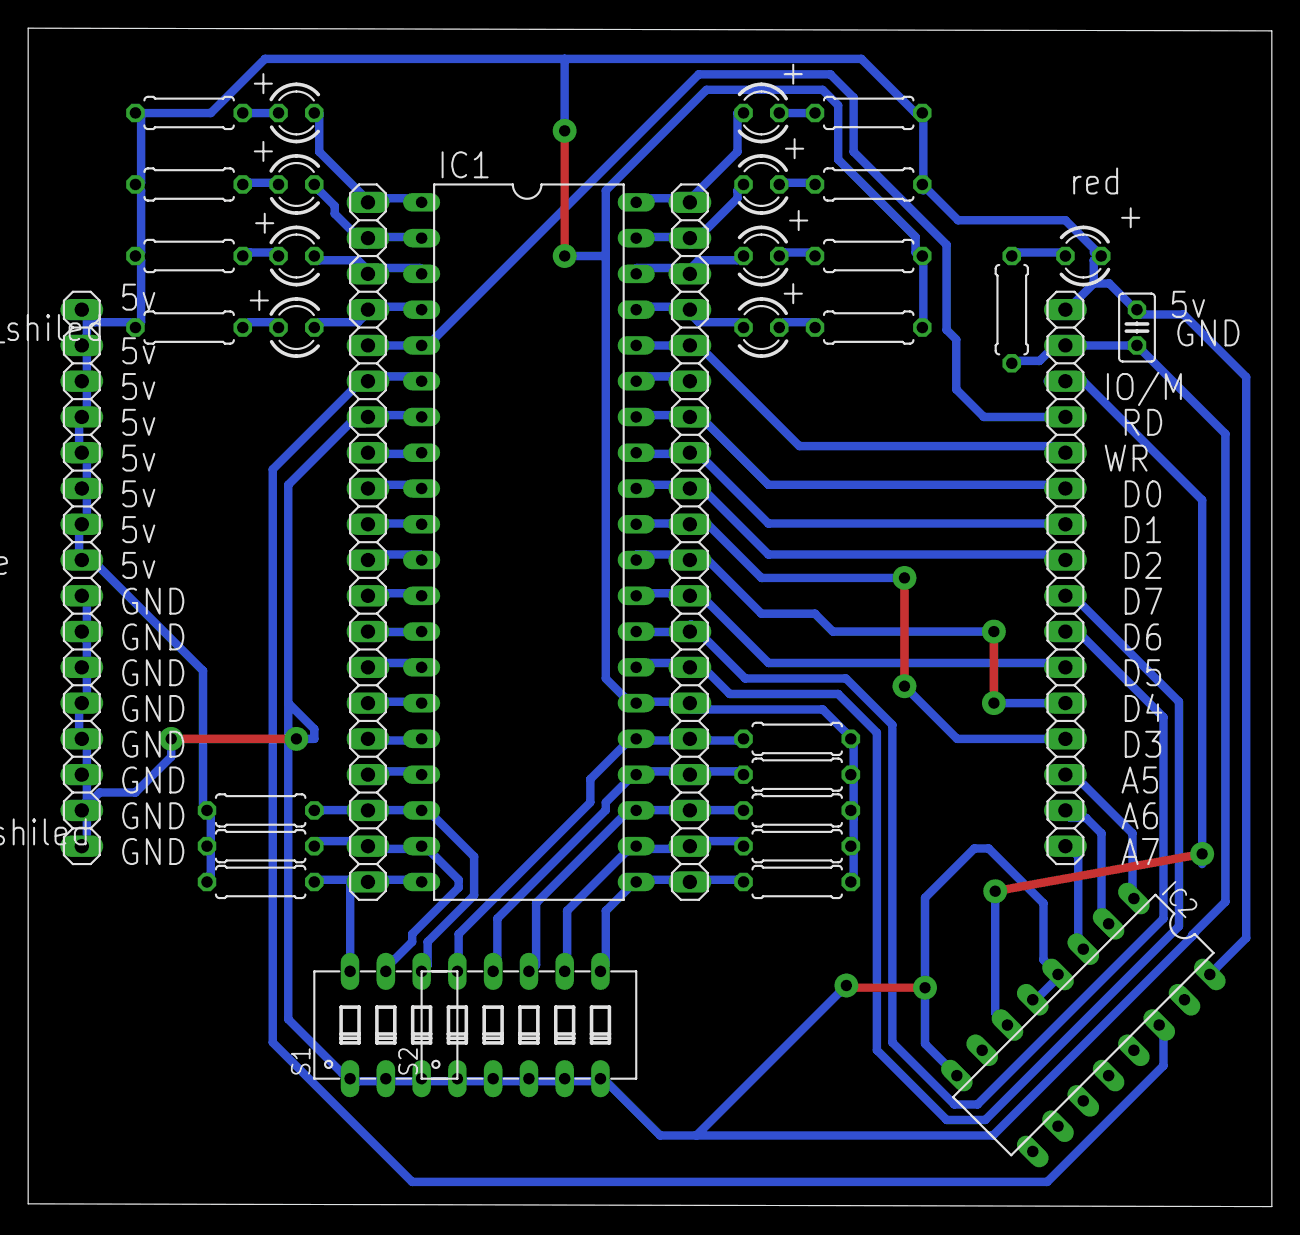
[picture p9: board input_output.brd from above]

Board: 2 copper layers, 88.3 x 83.7 mm, 35 parts (0 on the bottom side), 53 nets.
